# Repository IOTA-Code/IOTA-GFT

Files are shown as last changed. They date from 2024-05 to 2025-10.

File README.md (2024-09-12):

# IOTA-GFT Project
----------------------------
The IOTA-GFT project (IOTA GPS Flash Timer) implements a GPS based solution for adding UTC timestamps to sequential image captures (e.g. video).  The project includes both an IOTA-GFT hardware device and various software components for the computer used to capture the video data.

The IOTA-GFT device connects to the video recording computer and drives an LED which is attached to the front of the optics.  The IOTA-GFT software on the recording computer controls the LED flash sequence from the device and logs the timing information from the IOTA-GFT device.  After recording a video sequence, this recording computer IOTA-GFT software analyzes the video and timing log to determine the times for each video frame.

This repository includes the following components:
- IOTA-GFT Device
    - Device Firmware
    - IOTA-GFT Shield PCB design
    - LED bracket components
- Recording computer software ( *** NOT YET ADDED TO THIS REPO ! )
    - ASCOM Driver for the IOTA-GFT device
    - FileStamper utility for inserting timestamps
- Documentation
    - Usage Guide(s) - also TBD !

## Licensing
------------
 This program is free software: you can redistribute it under the terms of the GNU General Public License as published by the Free Software Foundation, either version 3 of the License, or (at your option) any later version.  However, if you wish to make modifications, we add a further restriction.  If you make changes to the code from this repository, you must agree to NOT use the modified code for timing occultation observations.

 This program is distributed in the hope that it will be useful, but WITHOUT ANY WARRANTY; without even the implied warranty of MERCHANTABILITY or FITNESS FOR A PARTICULAR PURPOSE.  See the GNU General Public License for more details.

## Developers & Contributors
----------------------------

- Bob Anderson
- Steve Preston

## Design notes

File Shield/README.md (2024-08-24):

# IOTA-GFT Shield
----------------------------
The IOTA-GFT Arduino shield includes the GPS receiver and driver circuit for the LED.  This shield is designed for and requires an Arduino Mega 2560 R3 board.  The IOTA-GFT controller consists of this shield mounted on an Arduino Mega.  This repository carries the Eagle design files for the shield.

## Components
--------------
- IOTA-GFT shield PCB
- Female stacking headers for Arduino Mega ( https://a.co/d/8ICgdAu )
- GT-U7 GPS breakout board based on ublox GPS receiver (https://a.co/d/9eoqRfC) 
- Active GPS Antenna + pigtail ( https://a.co/d/hI4Iglh )
- SparkFun Voltage-Level Translator Breakout - TXB0104 ( https://www.sparkfun.com/products/11771 )
- (2) seven pin male headers - 0.1" (can break off from longer header : https://a.co/d/7kpX5g9 )
- (1) six pin male header - 0.1"
- (2) JST-XH PCB jack , CONN HEADER VERT 2POS 2.5MM, JST part# B2B-XH-A ( https://www.digikey.com/short/nwvmtq8r )
- Resistors (1/4w)
  - (1) 150 ohm
  - (1) 1k ohm
  - (1) 5.6k ohm
  - (1) 200k ohm
- Capacitors (50v)
  - (1) 30 pf
- Transistors
  - (1) 2N3906
- Plastic zip tie (4")

## Schematic and Board layout
------------
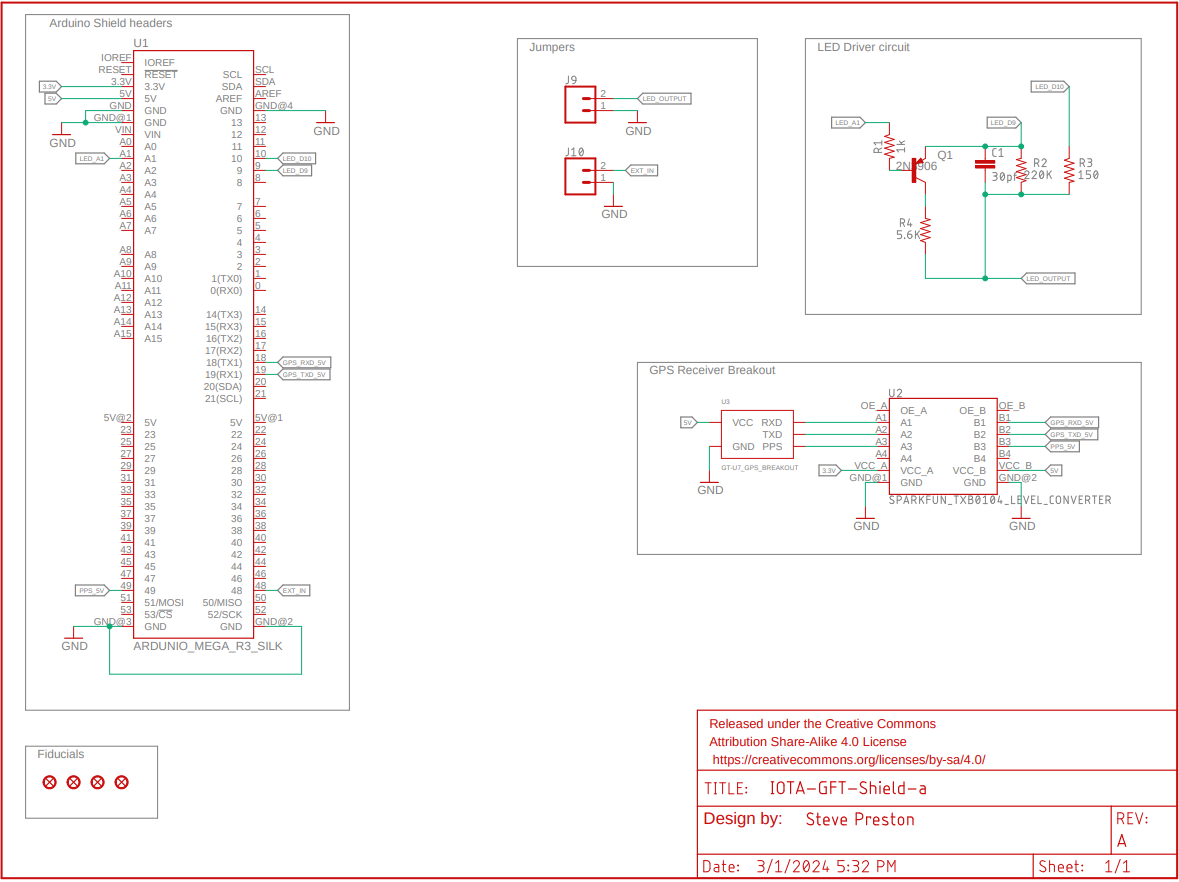
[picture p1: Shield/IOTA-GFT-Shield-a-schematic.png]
schematic

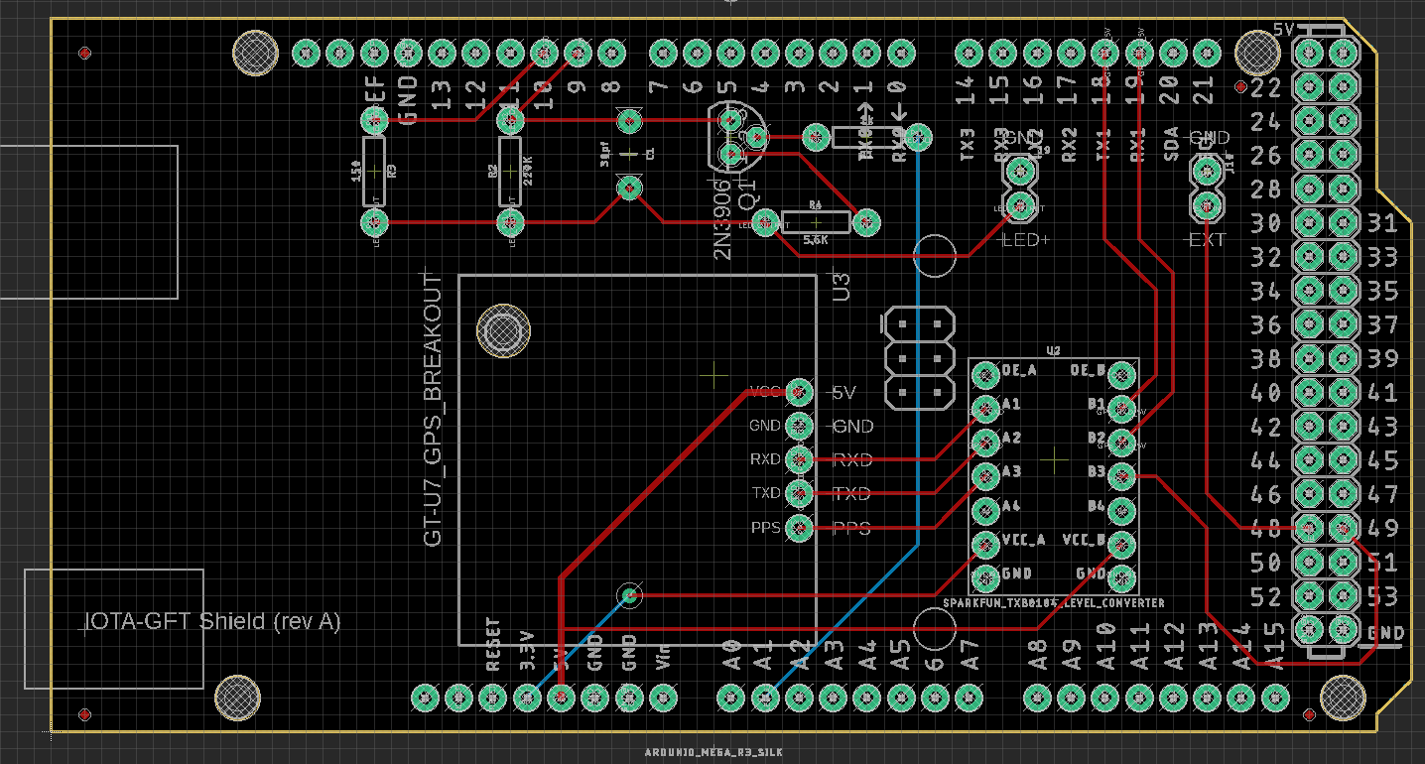
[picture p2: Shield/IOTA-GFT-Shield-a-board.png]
board layout


## Assembly
------------
- Solder the Arduino shield stacking headers onto the PCB.
- Solder the two 7 pin male headers onto the PCB at the location of U2 (level shifter)
- Solder the one 6 pin male header onto the PCB at the location of the pins for the GT-U7 breakout board.
- Solder the resistors, capacitor, and transitor onto the PCB at the marked locations.
- Solder the two JST connectors onto the PCB with the open side facing away from the Arduino's USB and power connectors.
- Solder the TXB0104 breakout board onto the two male headers with the OE marked end facing the two JST connectors.
- Attach the GPS antenna pigtail to the antenna connector on the GT-U7 breakout board.
- Solder the GT-U7 GPS breakout board to the single six pin male header.
- Snug down the GPS antenna pigtail to the breakout board using the plastic zip tie.

## Licensing
------------
 This design is free: you can redistribute it under the terms of the GNU General Public License as published by the Free Software Foundation, either version 3 of the License, or (at your option) any later version.  However, if you wish to make modifications, we add a further restriction.  If you are going to use this design to measure times for occultation observations, you must agree to not modify the design.

 This design is distributed in the hope that it will be useful, but WITHOUT ANY WARRANTY; without even the implied warranty of MERCHANTABILITY or FITNESS FOR A PARTICULAR PURPOSE.  See the GNU General Public License for more details.

## Developers & Contributors
----------------------------
- Bob Anderson
- Steve Preston
- Aart Olsen

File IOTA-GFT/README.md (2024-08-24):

# IOTA-GFT Device
----------------------------
The IOTA-GFT device connects to the user's computer via USB and drives an LED which is attached to the front of the telescope.  The user's computer initiates sequences of LED "flashes" which illuminate a set of frames on recorded video sequences.  The IOTA-GFT device employs an internal GPS receiver to record the timing of the flash sequences and emit a log with timing information to the user's computer over the USB connection.  This same USB connection supplies power to the IOTA-GFT device. After video recording, this timing log is compared to the recorded video to determine the UTC times for each frame of the video recording.

The IOTA-GFT device hardware includes the following components:
- IOTA-GFT controller, USB cable, enclosure and USB cable
- Active GPS antenna
- LED bracket and 3.5mm pin cable

This repository holds the Arduino firmware for the IOTA-GFT controller.  The IOTA-GFT controller combines an Arduino Mega 2560 with the IOTA-GFT shield.

## Building and installing the IOTA-Flasher firware
---------------------------------------------------
Prerequisites:
- Arduino IDE

Build and Install Steps:

Open the file "IOTA-GFT.ino" in the Arduino IDE.  Connect the IOTA-GFT device to your build computer via USB.  Then, in the Arudino IDE, connect to the IOTA-GFT device and upload the firmware (this will automatically start with a build before uploading).

## Licensing
------------
 This program is free software: you can redistribute it under the terms of the GNU General Public License as published by the Free Software Foundation, either version 3 of the License, or (at your option) any later version.  However, if you wish to make modifications, we add a further restriction.  If you are going to use this device to measure times for occultation observations, you must agree to not modify the code from this repository.

 This program is distributed in the hope that it will be useful, but WITHOUT ANY WARRANTY; without even the implied warranty of MERCHANTABILITY or FITNESS FOR A PARTICULAR PURPOSE.  See the GNU General Public License for more details.

## Developers & Contributors
----------------------------
- Bob Anderson
- Steve Preston

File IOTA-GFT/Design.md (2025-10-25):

# IOTA-GFT Design Document
This design document provides an overview of the basic theory of operation for the IOTA-GFT device.  
## Components
The IOTA-GFT comprises the following components:
- PIC microprocessor (Arduino Mega 2560)
- GPS receiver (ublox)
- Serial I/O to an external computer via USB
- LED driver circuit for driving an external LED
- Optional input from an external 5V logic trigger signal
## General Overview
The IOTA-GFT collects timing information from the PIC microprocessor, the GPS receiver, and (optionally) the external trigger input.  This timing information, or timing log, is sent across the USB connection to the recording computer where it is stored and later used to determine the UTC time of various system events.  Each line of output in this timing log, from the IOTA-GFT device, includes a timestamp and a data content portion.  The log timestamps are 32 bit counts (in hex) from the 16mhz system timer of the PIC processor. The IOTA-GFT emits logging sentences with the system time for each of the following system events:
- GPS data
    - NMEA sentences via serial I/O comm with the GPS receiver
    - PPS via 1pps signal generated by the GPS receiver
- LED activity
    - LED turns ON
    - LED turns OFF
- External input trigger (EXP signal)
- USB Commands
    - USB Commands sent to the device
    - Device responses to USB Commands 
## Operating Modes
The IOTA-GFT firmware implements a simple state machine with five "operating modes": InitMode, WaitingForGPS, Syncing, TimeValid, and FatalError.  The device boots into InitMode and quickly transitions to WaitingForGPS.  In WaitingForGPS mode, the code monitors the NMEA data and PPS signal waiting until both of these inputs imply that the GPS data is deemed "valid" for timing purposes.  At this point, the device moves to "Syncing" mode where it monitors several seconds of data to confirm that the GPS data is stable.  Assuming the GPS data looks good for several seconds of Syncing mode, the device moves to TimeValid mode and is ready for operation.  If transient errors occur (e.g. bad NMEA data or missing PPS pulses), the device will drop back to WaitingForGPS mode to "restart" toward TimeValid mode.  The FatalError mode only occurs in case of a non-recoverable error (e.g. unable to initialize the GPS receiver).State changes, between the five operating modes, are primarily driven by the GPS receiver - both the NMEA data and the PPS interrupt.

The IOTA-GFT firmware follows the standard Arduino coding structure: a one-time setup() routine and a loop() routine which is exectued repeatedly.  The setup() routing initializes the GPS receiver, the Arduino timer/counters, the Arduino I/O ports and various other elements.  The loop() routine repeatedly checks for input from the GPS receiver and the USB serial from the recording computer.  In addition, the loop() routine regularly outputs pending timing log data to the recording computer. 

## Timers
IOTA-GFT uses five of the Arduino timer/counters: Timer 0, Timer 2, Timer 3, Timer 4 and Timer 5.

Timer 0 is the default Arduino timer for the delay() and millis() functions.  These functions are used in the gps communication code.

Timer 2 is used in PWM mode to implement a software based intensity control for the LED.

Timer 3 is used for LED pulse duration in certain flash modes.

Timer 4 and Timer 5 are synchronized system timer counters running at 16 mhz.  The Input Capture signal for Timer 4 is tied to the PPS input. The Input Capture signal for Timer 5 is tied to the EXP signal input.  The firmware uses the overflow interupts to implement 32 bit system timers based on Timer 4 and 5.  Because these timers are synchronized, both system time counts are always identical.  The input capture register assures that the PPS and EXP interupt times are highly accurate (no latency to the ISR routine).

## Logging buffer
All information which is output to the recording computer (via USB serial) is first placed in an internal buffer.  The buffer is output to the recording computer during each pass through the main loop() routine.  Most of the logging sentences will be written to the buffer without interruption.  However, logging based on PPS and EXP interrupts might "interrupt" another sentence in the log.

## Flash Operation
The IOTA-GFT is designed to support three flash modes: CLK, PPS and EXP.  The majority of users will use CLK flashes.  The EXP mode is currently in development.  It is aimed at cameras which provide an output signal marking the beginning of an exposure.  

IOTA-GFT operates in CLK flash mode by default.  Flash sequences are specified as X seconds long.  When a "flash now" command is sent to the device in CLK mode, the LED turns on immediately and turns OFF X seconds later according to the internal device clock.

In either flash mode, the device can be programmed to a wide range of flash intensity values.

In addition, there is an option to turn the LED ON and OFF via explicit commands from the recording computer (over the USB port).

## LED Driver Circuit
The LED intensity is controlled via two appoaches: a LED current control "driver" circuit and a PWM modulation of the power driving this LED driver circuit.  The LED driver circuit is documented in the schematic for the PCB.

## USB I/O Device Commands
The recording computer sends commands to the IOTA-GFT over the USB connection. Commands are terminated with a LF (linefeed) character ('\n').  The commands may optionally include an XOR checksum in the form of "*XX" where XX are two ASCII hex chars for the one byte checksum. Commands are NOT case sensitive.

IOTA-GFT will return two sentences to all commands.  The first sentence will be an echo of the command sent to the device.  The second sentence will be a response to the command and include a simple one byte XOR checksum (two ASCII hex chars) at the end, followed by CR,LF ('\r\n'). Successful responses will be either the sentence "[DONE]" or "[command: value]".  Error responses will be of the form "[ERROR ...".  

### general commands
    status - get current device mode (e.g. TimeValid, WaitingForGPS, Syncing, etc)
    device - get device name
    version - get version info for the device
    null - ignore this command string if it includes the word "null" - useful for clearing the input buffer

 ### flash commands
    flash now - start flash sequence at the next PPS or EXP pulse
    flash duration X - X is seconds in PPS mode or starting number of pulses in EXP mode
    flash level X - get/set the current flash intensity level [ 0 to 255]
    flash range [X] -get/set the current range of flash intensity to low, medium or high [ 0 to 2]
    flash mode [clk | pps | exp ] - get/set the current flash mode (CLK, PPS or EXP)

    pulse duration [X] - get/set the flash pulse duration (us)
    pulse interval [X] - get/set the flash pulse interval = # of exp interrupts between pulse sequences

    led [ON | OFF] - turn the LED on/off right now

 ### logging commands
    log [on | off ] - enable disable data logging (default = ON)

## Timing Log Format
After startup, the IOTA-GFT constantly emits logging information - a timing log.  The timing log includes all NMEA data from the GPS receiver, all PPS and EXP interrupts, all LED flash timing, all commands sent to the device, all responses to these commands, and a regular report on the current operating mode of the device.  Each of these outputs is in the form of a single line of ASCII characters terminated with a *XX checksum and CRLF characters.

### Operating mode sentence
IOTA-GFT will output an operating mode sentence at the start of each set of NMEA sentences (which occur at the beginning of each UTC second).  

The format (excluding the terminating CRLF):

{MODE LED=L fff mmm}*XX
- L = current status of LED, 0=OFF, 1= ON
- fff = current flash mode (CLK, PPS or EXP)
- mmm = operating mode 
- XX = hex checksum in ASCII

examples: 
- {MODE LED=0 CLK Sync}*11
- {MODE LED=0 CLK TimeValid}*55

At power-up, IOTA-GFT emits the following sentence to the logging stream:

[STARTING!]*27

### GPS NMEA sentences
IOTA-GFT outputs a log sentence for each of the following NMEA sentences: $GPDTM, $GPRMC, $GPGGA, $PUBX04 (proprietary ublox sentence).  

The format (excluding terminating CRLF):

{TTTTTTTT nnn}*XX
- TTTTTTTT = 8 digit Hex system timer count when NMEA data received
- nnn = NMEA sentence data (without terminating CR or LF)
- XX - hex checksum in ASCII

examples:
- {006F03C0 $GPDTM,W84,,0.0,N,0.0,E,0.0,W84*6F}*37
- {00702831 $GPRMC,211252.00,A,4738.34269,N,12214.22164,W,0.114,,- 140324,,,A*64}*41
- {00725188 $GPGGA,211252.00,4738.34269,N,12214.22164,W,1,08,1.14,32.3,M,-18.7,M,,*51}*7C
- {0074B4E8 $PUBX,04,211252.00,140324,421972.00,2305,18,-305489,101.109,21*3D}*6A

### Interrupt timing sentences
An interrupt timing sentence is logged at the time of PPS and EXP interrupts.  These interrupt sentences are injected into the logging buffer at "interrupt level" and may sometimes appear "inside" other sentences (interrupting another logging sentence).

The format (excluding terminating CRLF):

{TTTTTTTT P}*XX
- TTTTTTTT = 8 digit Hex system timer count at time of interrupt
- P => this is a PPS interrupt
- XX - hex checksum in ASCII

{TTTTTTTT E}*XX
- TTTTTTTT = 8 digit Hex system timer count at time of interrupt
- E => this is an EXP interrupt
- XX - hex checksum in ASCII

Example:
- {1550D7B3 P}*75

### Flash timing sentences
A flash timing sentence is logged whenever the LED changes state (from OFF to ON or from ON to OFF).

The format (excluding terminating CRLF):

{TTTTTTTT +}*XX
- TTTTTTTT = 8 digit Hex system timer count when flash changed state
- '+' => LED turned ON
- XX - hex checksum in ASCII

{TTTTTTTT !}*XX
- TTTTTTTT = 8 digit Hex system timer count when flash changed state
- ! => LED turned OFF at the end of a flash sequence
- XX - hex checksum in ASCII

{TTTTTTTT -}*XX
- TTTTTTTT = 8 digit Hex system timer count when flash changed state
- '-' => LED turned OFF as part of a multi-flash sequence
- XX - hex checksum in ASCII

Example:
- {1550D7CB +}*7E

### Commands/Responses
Commands sent to the device will be echoed to the logging stream and enclosed in square brackets ('[', ']') and starting with the phrase CMD and a terminating checksum.  Responses to these commands are also returned in square backets and include a checksum.

example:
- [CMD flash now]*4A
- [DONE]*06

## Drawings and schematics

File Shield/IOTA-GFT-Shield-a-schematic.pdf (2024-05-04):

5V 5V | RESET RESET | A0 A0 | A1 A1 | A2 A2 | A3 A3 | A4 A4 | A5 A5 | A6 A6 | A7 A7 | A8 A8 | A9 A9 | A10 A10 | A11 A11 | A12 A12 | A13 A13 | A14 A14 | A15 A15

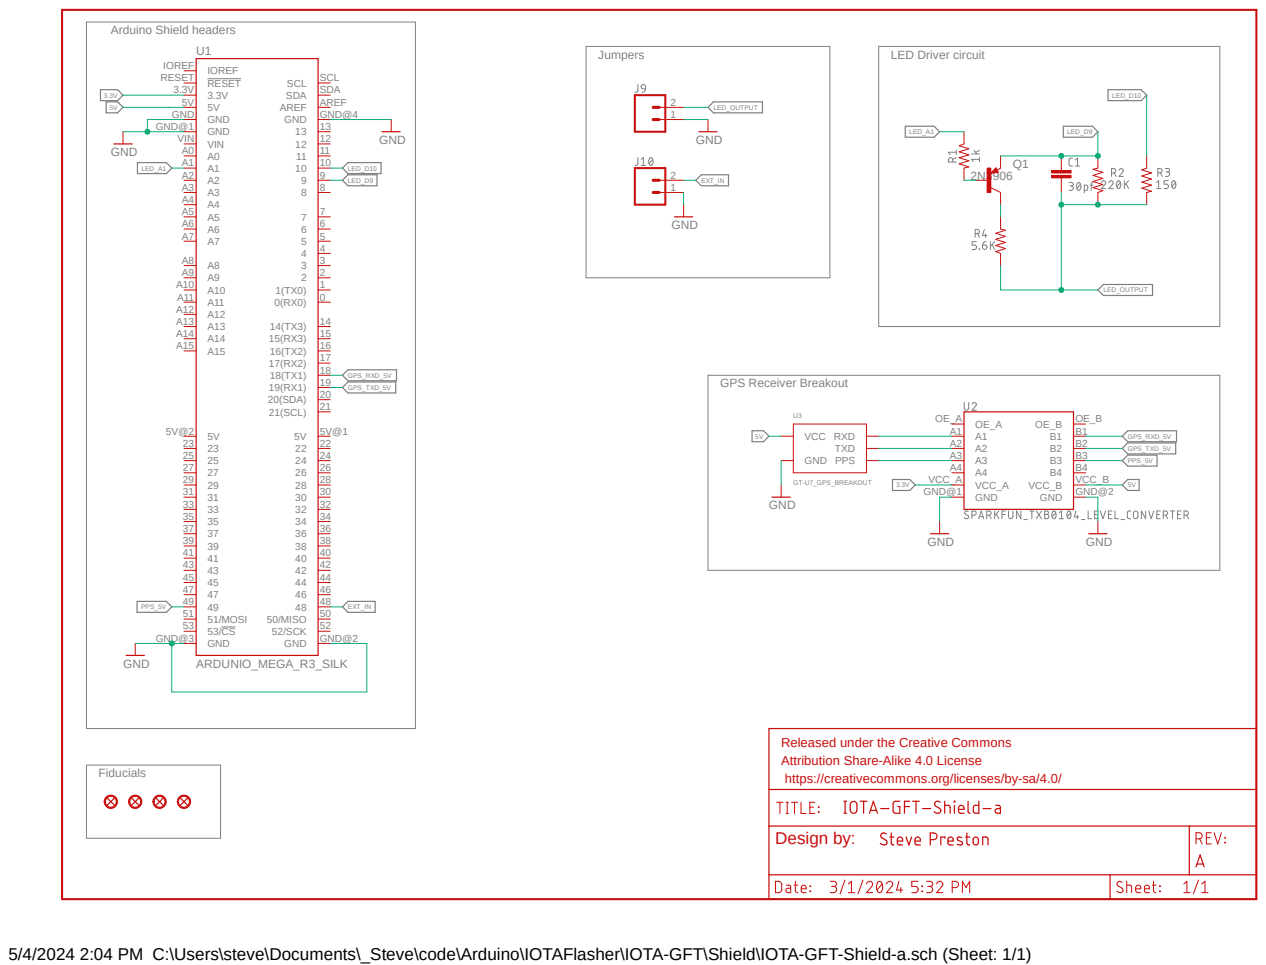
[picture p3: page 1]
Jumpers; LED Driver circuit; Fiducials; GND; ARDUNIO_MEGA_R3_SILK; GNDGT-U7_GPS_BREAKOUT; 14 GND GND@1; 52/SCK; 52 51/MOSI 51; 50/MISO; AREF; 21(SCL); 21 20(SDA); VIN VIN; 0 GND; GND@4 GND GND; SDA; SDA SCL; SCL IOREF IOREF; 5V@1 GND GND@3; GND@2; B4 VCC_B; VCC_B; VCC_A VCC_A; GND GND@1; GND@2 VCC GND; RXD TXD; PPS U3; LED_D9; LED_D10; LED_A1; LED_OUTPUT; LED_OUTPUT EXT_IN; EXT_IN; GPS_RXD_5V GPS_RXD_5V; GPS_TXD_5V GPS_TXD_5V; PPS_5V; Released under the Creative Commons; Design by:

Arduino Shield headers

GPS Receiver Breakout

Attribution Share-Alike 4.0 License
https://creativecommons.org/licenses/by-sa/4.0/

5/4/2024 2:04 PM C:\Users\steve\Documents\_Steve\code\Arduino\IOTAFlasher\IOTA-GFT\Shield\IOTA-GFT-Shield-a.sch (Sheet: 1/1)

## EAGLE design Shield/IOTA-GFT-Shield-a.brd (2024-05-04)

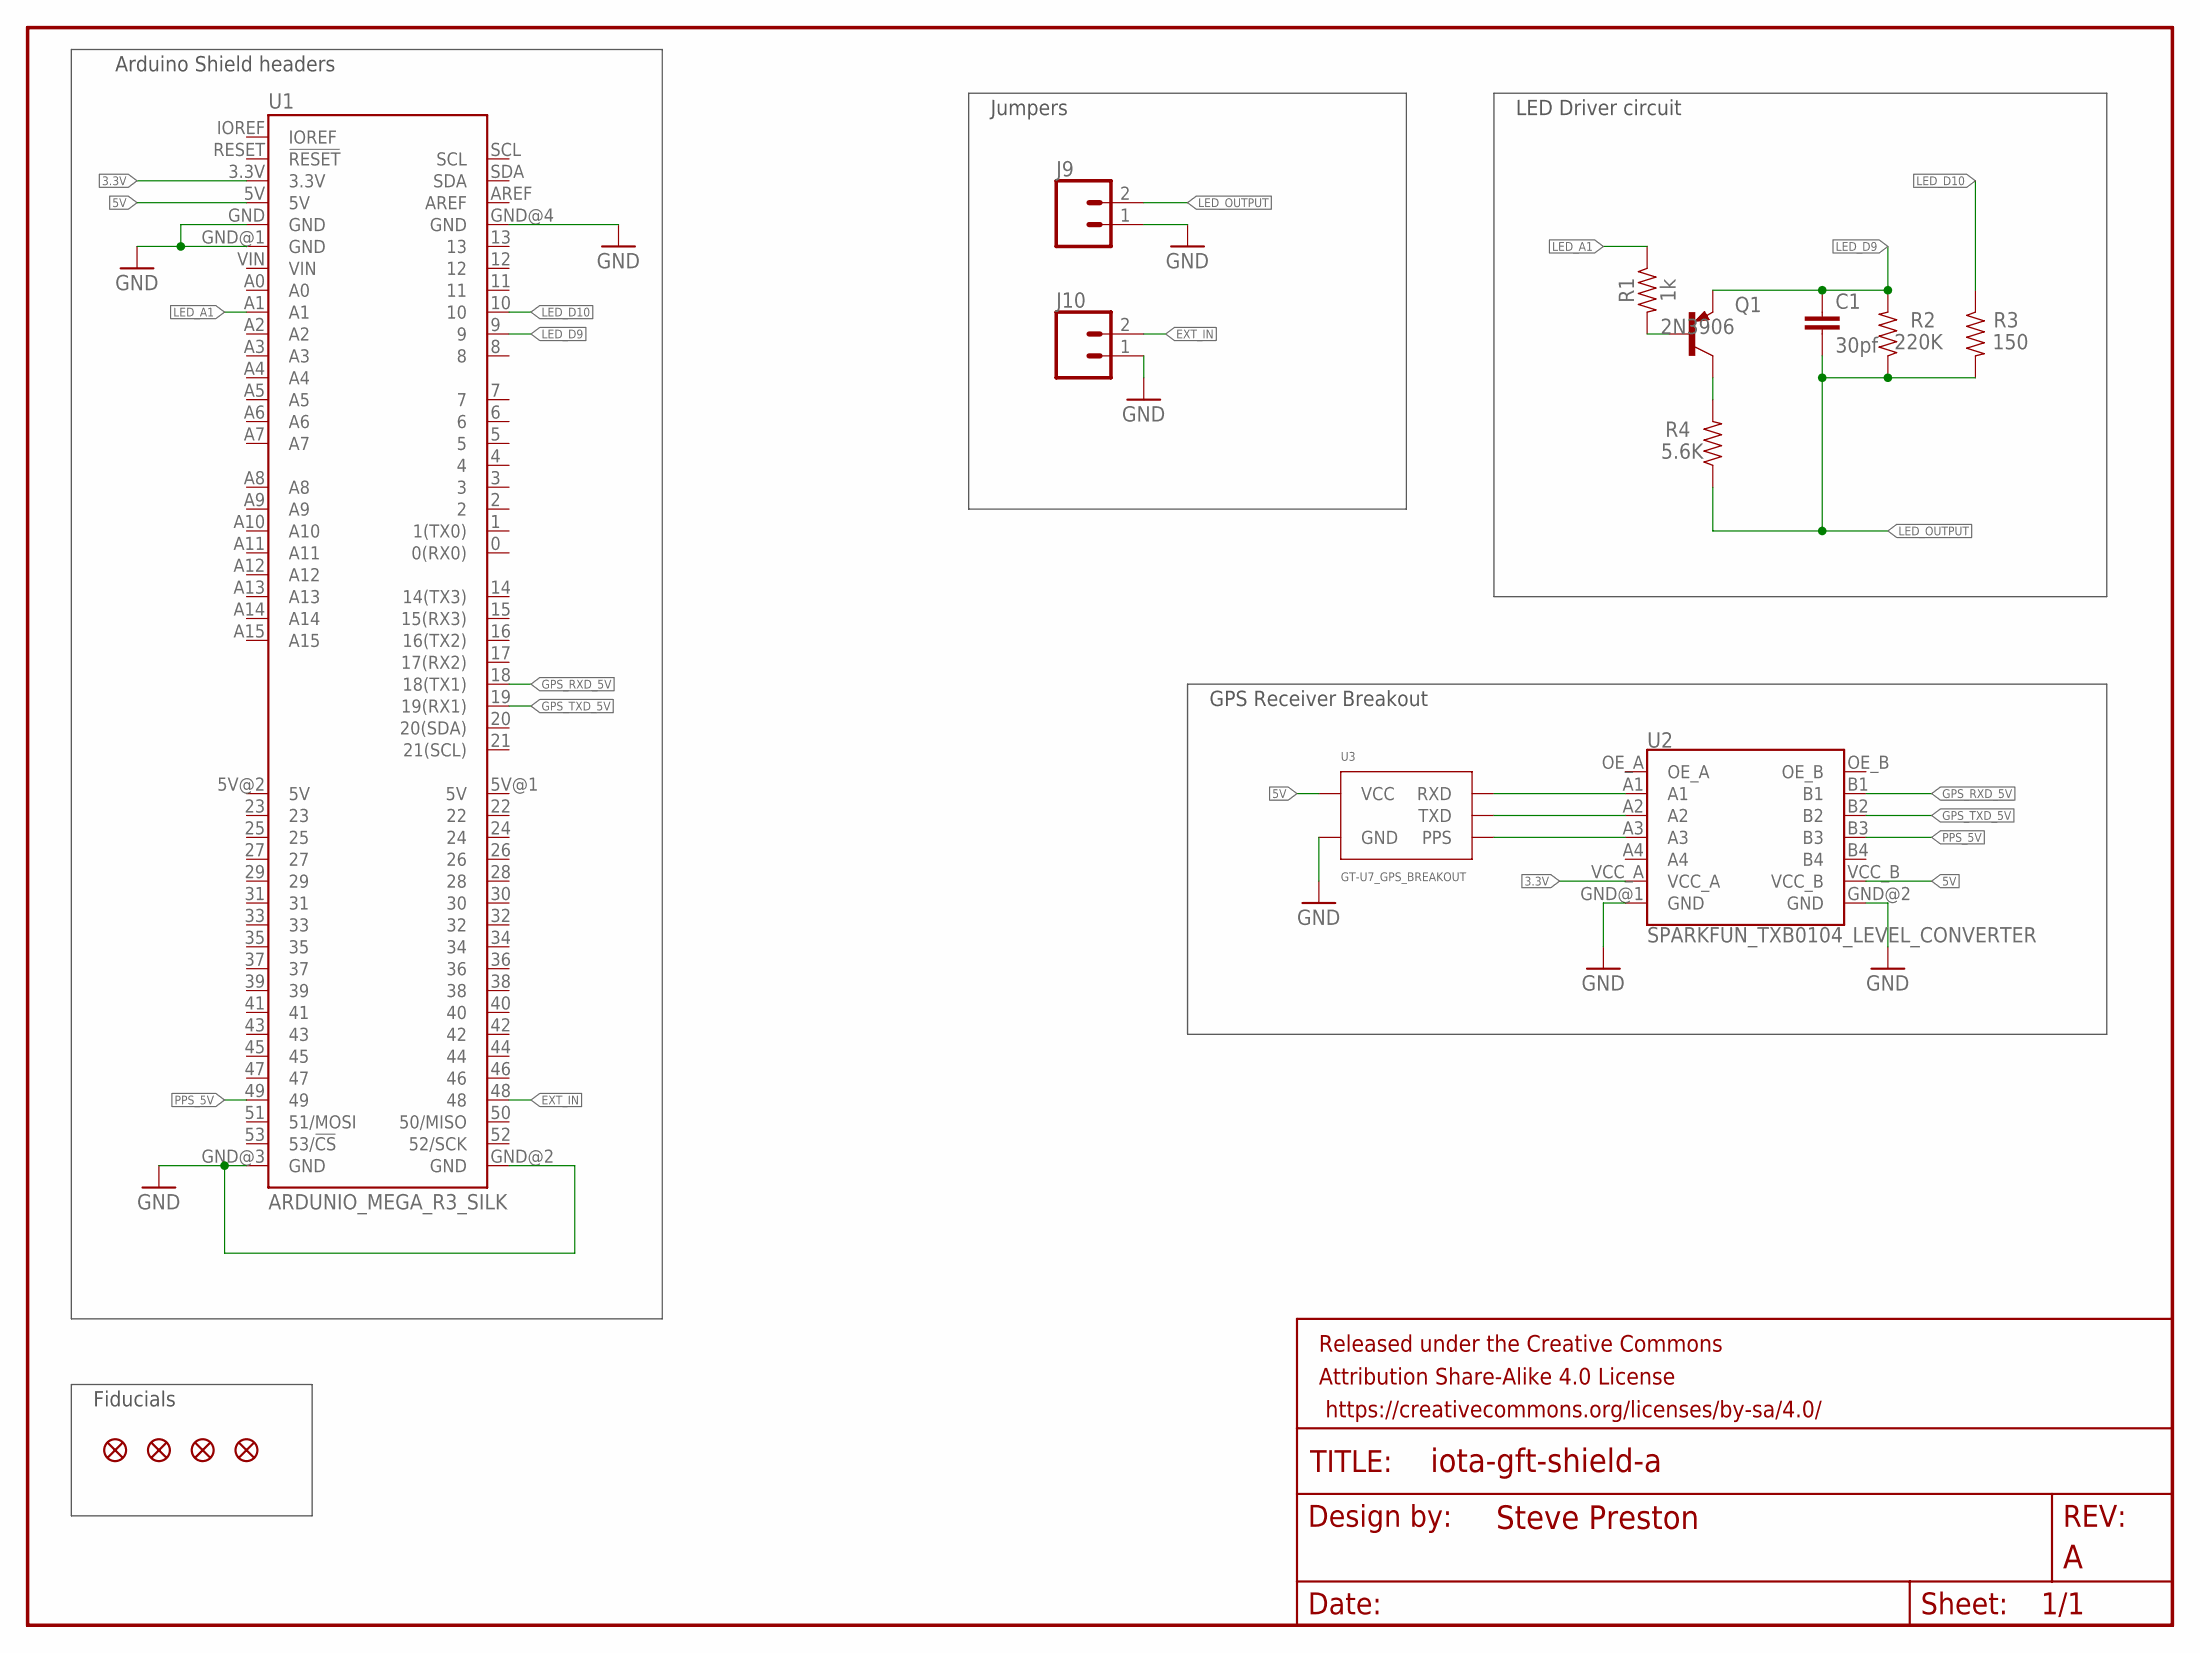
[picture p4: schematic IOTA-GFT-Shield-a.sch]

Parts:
C1: 30pf; CAP-PTH-5MM
FD1, FD2, FD3, FD4: FIDUCIALUFIDUCIAL; FIDUCIAL-MICRO
FRAME1: FRAME-LETTER; CREATIVE_COMMONS
J9, J10: CONN_02; 1X02
Q1: 2N3906; TO92
R1: 1k; AXIAL-0.3
R2: 220K; AXIAL-0.3
R3: 150; AXIAL-0.3
R4: 5.6K; AXIAL-0.3
U1: ARDUNIO_MEGA_R3_SILK; ARDUINO_MEGA_SILK
U2: SPARKFUN_TXB0104_LEVEL_CONVERTER; TXB0104_LEVEL_CONVERTER
U3: GT-U7_GPS_BREAKOUT; GT-UT

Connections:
3.3V: U1.3.3V, U2.VCC_A
5V: U1.5V, U2.VCC_B, U3.VCC
EXT_IN: J10.2, U1.48
GND: J9.1, J10.1, U1.GND, U1.GND@1 (GND), U1.GND@2 (GND), U1.GND@3 (GND), U1.GND@4 (GND), U2.GND@1 (GND), U2.GND@2 (GND), U3.GND
GPS_RXD: U2.A1, U3.RXD
GPS_RXD_5V: U1.18 (18(TX1)), U2.B1
GPS_TXD: U2.A2, U3.TXD
GPS_TXD_5V: U1.19 (19(RX1)), U2.B2
LED_A1: R1.P$1 (1), U1.A1
LED_D9: C1.1, Q1.3 (E), R2.P$2 (2), U1.9
LED_D10: R3.P$1 (1), U1.10
LED_OUTPUT: C1.2, J9.2, R2.P$1 (1), R3.P$2 (2), R4.P$1 (1)
unnamed: Q1.1 (C), R4.P$2 (2)
unnamed: Q1.2 (B), R1.P$2 (2)
PPS: U2.A3, U3.PPS
PPS_5V: U1.49, U2.B3

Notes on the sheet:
Jumpers
LED Driver circuit
Arduino Shield headers
GPS Receiver Breakout
Fiducials

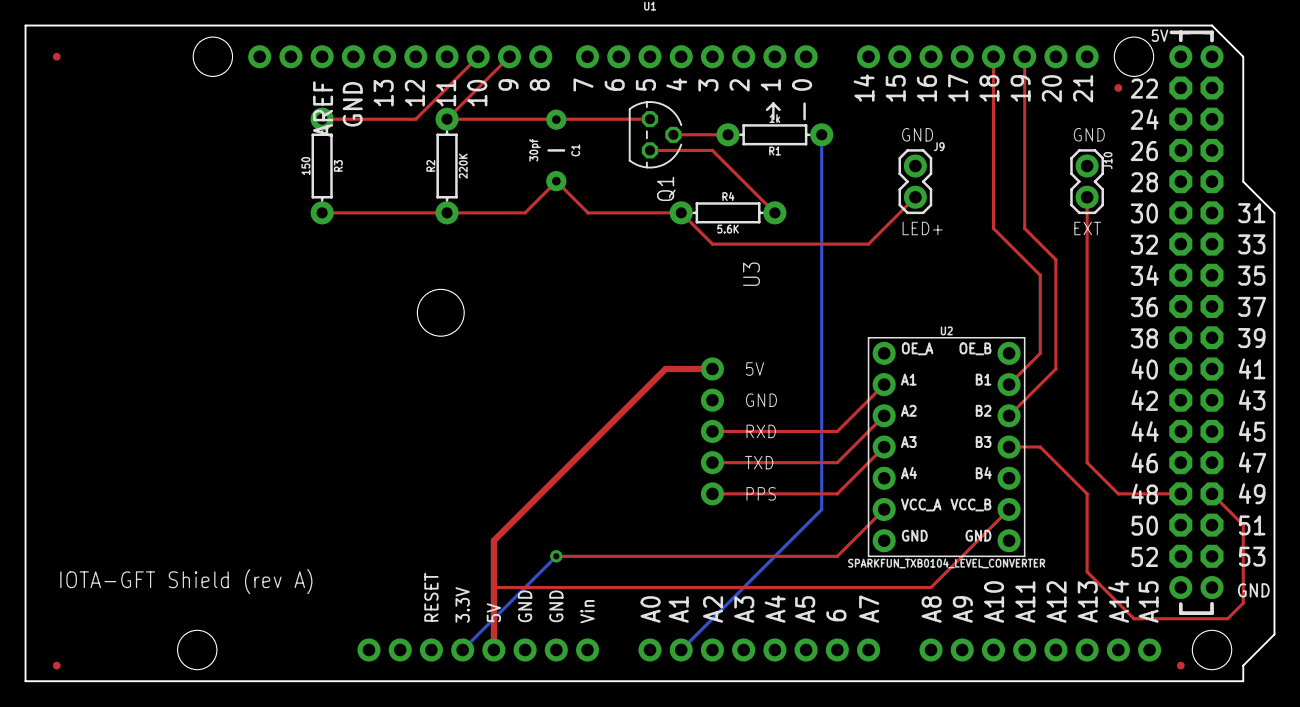
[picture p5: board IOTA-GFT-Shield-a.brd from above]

Board: 2 copper layers, 101.6 x 53.3 mm, 16 parts (0 on the bottom side), 16 nets.

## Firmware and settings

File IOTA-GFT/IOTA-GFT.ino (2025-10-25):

//======================================================================
//  IOTA-GFT - GPS Exposure TIME LOGGER
//  
//  NOTES: 
//  *** ASSUMES NEO-6 GPS module
//  *** ASSUMES MEGA2560 R3 Arduino
//   
//
//====================================================================== 
//
//

// Mega Pin Connections
//
//  GPS comm
//   Connect the GPS TX (transmit) to Digital pin 19 (RX1)
//   Connect the GPS RX (receive) to Digital pin 18 (TX1)
//   Connect the GPS 1pps Digital pin 49 (ICP4)
//
//	Exposure start signal
//   Connect the Digital pin 48 to the exposure interrupt input (or GND if no exposure int input).  Most cameras will require a pull-up resistor.
//
//  LED
//   Connect Digital pin 9, Digital pin 10, and Analog pin 1 to the LED driver circuit
//   
//
// 


//=======================================
//  INCLUDES
//=======================================
#include "iota-gft.h"
#include "ublox.h"
#include "gpsComm.h"
#include "logger.h"
#include "usbComm.h"

//==========================================
// PIN definitions
//===========================================
int PPS_PIN = 49;           // PPS signal input from GPS
int EXP_PIN = 48;           // EXP signal input from camera

  // LED circuit pins
#define flashPinB 9        // This PWM pin is controlled by OCR2B
#define flashPinA 10       // This PWM pin is controlled by OCR2A

#define midRange  55       // Controls switch transistor that provides middle current for LED (D55 = Analog 1)

//=======================================
//  GLOBAL variables and definitions
//=======================================

//  VERSION
//
const char *strDeviceName = "IOTA-GFT";
const char *strVersion = "v2024-04-01-01";

volatile OperatingMode DeviceMode;    // current operating mode
volatile bool blnReportMode;          // true => report current mode in log (enabled with each NMEA set)

unsigned long tBeginWait;
bool fStarted;                        // set to true when we first enter TimeValid mode


volatile FlashingMode FlashMode;		// current flashing mode

short int SYNC_SECONDS = 4;            // # of seconds for syncing to GPS time
volatile short int TimeSync;          // ( > 0 ) => we are syncing to GPS sentence times = # of seconds remaining for sync (small value so no problem with ints)



//******************
// Timers
//

volatile unsigned short timer4_ov;    // timer 4 overflow count = high word of "time" (32ms)
volatile unsigned short timer5_ov;    // timer 5 overflow count  

byte flashlevel = 255;                    // flash brightness level in percent (0 to 255)
byte flashrange = 2;                      //  range of flash intensity ( 0 - 2 )

uint16_t Timer3_us = 16;				          // microseconds per led timer clock count (x256 prescaler)
uint16_t OCR3A_pulse = 5000/Timer3_us;    // default 5ms pulse duration for EXP mode

//*************
//  Time
//
volatile unsigned long Timer_Second = 2000000;                // # of ticks for 1 second
volatile unsigned long PPS_TOLERANCE = 2000;                  // tolerance for PPS interval - 1ms
volatile unsigned long CLOCK_TOLERANCE = 20000;               // tolerance for arduino clock frequency interval - currently 10ms

volatile unsigned long tk_pps_interval_total=0;         // sum of pps intervals
volatile unsigned long tk_pps_interval_count=0;         // # of pps interval
volatile unsigned long tk_pps_interval_ave=0;           // average pps interval

// YY-MM-DD HH:MM:SS time of current second
//   note: all values are less than 255 => don't need to protect individual changes from interrupts during read/write
//         an ISR might use these values, so we should only update the groups of these variables with interrupts OFF
//
volatile bool time_UTC = false;         // true => time is currently UTC , false => time is currently GPS
volatile int sec_Year;                  // 2 digit
volatile int sec_Mon;
volatile int sec_Day;
volatile int sec_hh;
volatile int sec_mm;
volatile int sec_ss;
volatile int offsetUTC_Default = -1;      // receiver default value for GPS-UTC offset
volatile int offsetUTC_Current = -1;      // current/valid GPS-UTC offset


//***************
// PPS globals
//
volatile unsigned long tk_PPS = 0;        // tick "time" of most recent PPS int

//****************************
// Flash variables
//    There are three flashing modes: CLK, PPS and EXP.  In all cases, the LED is driven by a PWM cycle.
//    CLK mode => Flashes are single LED On/Off sequences (via PWM) where the LED is turned ON immediately and turns off after X seconds according to the internal clock.
//    PPS mode => Flashes are single LED On/Off sequences (via enabing/disabling PWM) where both the start and stop are closely aligned with a PPS signal.
//    EXP mode => Flashes are a series of short duration LED On/Off pulses
//    
//
volatile boolean LED_ON = false;      			// LED state

volatile int PPS_Flash_Countdown_Sec;           // # of seconds remaining in a PPS or CLK flash
                                                //  (countdown < 0) => not in PPS or CLK flash sequence

                                            // EXP flash sequences are short pulses separated by D EXP intervals for a total count of X pulses
                                            //      sequence is enabled when pulse_countdown is non-zero
                                            //
int pulse_duration_us = 5000;               // duration of one shutter (EXP) pulse in EXP mode
volatile int pulse_interval = 5;            // number of EXP events between pulses
volatile int pulse_countdown;               // # of pulses left in sequence, 0 => no EXP flash sequence in progress, (< 0 => no sequence active)
volatile int pulse_interval_countdown;      // # of EXP events until next pulse, 0=> flash (pulse) on next EXP event



//*********
//  INPUTS
//
volatile bool blnEchoNMEA = false;


//********
//  serial outputs
//

char logPPS[] = "{TTTTTTTT P}*XX\r\n";
int len_logPPS = 17;
int offset_logPPS = 1;
int chksum_logPPS = 13;

char logEXP[] = "{TTTTTTTT E}*XX\r\n";
int len_logEXP = 17;
int offset_logEXP = 1;
int chksum_logEXP = 13;

char logFlashON[] = "{TTTTTTTT +}*XX\r\n";
int len_logFlashON = 17;
int offset_logFlashON = 1;
int chksum_logFlashON = 13;

char logFlashOFF[] = "{TTTTTTTT -}*XX\r\n";
int len_logFlashOFF = 17;
int offset_logFlashOFF = 1;
int chksum_logFlashOFF = 13;

char logFlashFINAL[] = "{TTTTTTTT !}*XX\r\n";    // end of final flash pulse in sequence
int len_logFlashFINAL = 17;
int offset_logFlashFINAL = 1;
int chksum_logFlashFINAL = 13;

// mode sentences
//
int lmode_logMode = 10;     // offset to start of led mode - to be set to 0 or 1
int fmode_logMode = 12;    // offset to start of flash mode string 

char logModeInit[] = "{MODE LED=L FFF Init}*1F\r\n";
int len_logModeInit = 26;
int chksum_logModeInit = 22;

char logModeWaitingForGPS[] = "{MODE LED=L FFF WaitingForGPS}*71\r\n";
int len_logModeWaitingForGPS = 35;
int chksum_logModeWaitingForGPS = 31;

char logModeSync[] = "{MODE LED=L FFF Sync}*02\r\n";
int len_logModeSync = 26;
int chksum_logModeSync = 22;

char logModeTimeValid[] = "{MODE LED=L FFF TimeValid}*XX\r\n";
int len_logModeTimeValid = 31;
int chksum_logModeTimeValid = 27;

char logModeFatal[] = "{MODE LED=L FFF Fatal}*7B\r\n";
int len_logModeFatal = 27;
int chksum_logModeFatal = 23;

char logERROR[] = "{ERROR 0000}*XX\r\n";
int len_logERROR = 17;
int offset_logERROR = 7;
int chksum_logERROR = 13;


//+++++++++++++++++++++++++++++++++++++++++++++++++++++++++++++++++++++++++++
//
//  INTERRUPT SERVICE ROUTINES
//
//    Timer 3
//      output compare for LED pulse duration
//    Timer 4
//      input capture for PPS logging
//      overflow for tracking clock count
//    Timer 5
//      input capture for EXP logging
//      overflow for tracking clock count
//+++++++++++++++++++++++++++++++++++++++++++++++++++++++++++++++++++++++++++


//========================================
// ISR for LED done (timer 3 output compare A interrupt)
//=========================================
ISR(TIMER3_COMPA_vect)
{
  unsigned long tk_LED;
  byte chk;

  // should be either CLK or EXP flash mode
  //
  if (FlashMode == CLK)
  {
    // CLK mode
    //  if done with seconds, turn OFF LED and log it
    //  if not done, reset timer and continue

    // check status of CLK flash sequence
    //  countdown >= 0 => in a flash sequence
    //  countdown == 0 => time to disable flash
    //  countdown < 0 => not in flash sequence now

    if (PPS_Flash_Countdown_Sec > 0)
    {
      // inside a flash sequence 
	    //	reenable timer for another second of LED ON
	    //
	  
      // start flash timer = timer 3
      TCCR3B = (1 << WGM32);                  // CTC set => mode 4 AND CS = 0 (no input => clock stopped)
      TCNT3 = 0;                              // start count at 0
      OCR3A = 0xFFFF;                         // set duration to 1 second
      TIFR3 = 0xFF;                           // clear any pending interrupts
      TCCR3B |= (1 << CS32);                  // f/256 clock source => timer is ON now   
      TIMSK3 |= (1 << OCIE3A);                // enable timer compare interrupt
	  
      // one less second left in this pulse
      //
      PPS_Flash_Countdown_Sec--;

    }
    else if (PPS_Flash_Countdown_Sec == 0)
    {
      // (Countdown == 0)  => flash should be disabled now
      //

      // if LED is ON, turn it OFF
      // else do nothing
      //
      if (LED_ON)
      {
        // no more flashes left
        //
        OCR2A = OCR2B = 0;                    // LED OFF
        tk_LED = GetTicks(CNT4);              // time LED turned OFF
        LED_ON = false;

        // LOG time LED went OFF
        //
        ultohexA(logFlashFINAL + offset_logFlashFINAL,tk_LED);
        chk = chksum_b(logFlashFINAL,chksum_logFlashFINAL-1);   // compute checksum
        btohexA(logFlashFINAL + chksum_logFlashFINAL, chk);
        LogTextWrite(logFlashFINAL,len_logFlashFINAL);


      }
      PPS_Flash_Countdown_Sec--;            //  decrement this count => no longer in flash sequence

    }  // end of check for seconds remaining

  }
  else if (FlashMode == EXP)
  {
    // EXP mode 
    //  end this pulse , update pulse count

    // turn OFF LED 
    //
    OCR2A = OCR2B = 0;
    LED_ON = false;

    // log time flash went off
    //
    tk_LED = GetTicks(CNT4);              // time LED turned OFF

    // turn OFF Timer 3
    //
    TCCR3B = (1 << WGM32);    // CTC set => mode 4 AND CS = 0 (no input => clock stopped)

    // note: interrupts are still disabled, so no issue with logging
    //
    if (pulse_countdown == 0)
    {
      ultohexA(logFlashFINAL + offset_logFlashFINAL,tk_LED);
      chk = chksum_b(logFlashFINAL,chksum_logFlashFINAL-1);   // compute checksum
      btohexA(logFlashFINAL + chksum_logFlashFINAL, chk);
      LogTextWrite(logFlashFINAL,len_logFlashFINAL);

      // all done with this pulse sequence now
      //
      pulse_countdown = -1;

    }
    else
    {
      ultohexA(logFlashOFF + offset_logFlashOFF,tk_LED);
      chk = chksum_b(logFlashOFF,chksum_logFlashOFF-1);   // compute checksum
      btohexA(logFlashOFF + chksum_logFlashOFF, chk);
      LogTextWrite(logFlashOFF,len_logFlashOFF);
    }

  }
  
} // end of LED_done_interrupt

//========================================
// ISR for Timer 4 overflow
//=========================================
ISR( TIMER4_OVF_vect)
{
  
  timer4_ov++;   // just increment overflow count
  
} // end of Timer4 overflow vector

//=================================================================
// PPS signal ISR
//
// ISR for Timer 4 input capture interrupt 
//==================================================================
ISR( TIMER4_CAPT_vect)
{

  unsigned long timeCurrent;
  unsigned long timePrev;
  unsigned long timeDiff;
  unsigned long ppsDiff;

  unsigned long tk_LED;       // LED time in ticks
  bool blnLogFlashON = false;
  bool blnLogFlashOFF = false;
  byte chk;

  
  //************************
  // Get TIME of PPS event from input capture register
  //
  timeCurrent = GetTicks(IC4);

  //*****************
  //  If init mode or FatalError, just leave...
  //
  if ((DeviceMode == FatalError) || (DeviceMode == InitMode))
  {
    // do nothing in these modes
    return;
  }

  // Check for start/end of LED pulse in PPS mode
  //
  //******************
  if (FlashMode == PPS)
  {

    // check status of PPS flash sequence
    //  countdown >= 0 => in a flash sequence
    //  countdown == 0 => time to disable flash
    //  countdown < 0 => not in flash sequence now
    if (PPS_Flash_Countdown_Sec == 0)
    {
      // (Countdown == 0)  => flash should be disabled now
      //

      // if LED is ON, turn it OFF
      // else do nothing
      //
      if (LED_ON)
      {
        // no more flashes left
        //
        OCR2A = OCR2B = 0;                    // LED OFF
        tk_LED = GetTicks(CNT4);              // time LED turned OFF
        LED_ON = false;

        // LOG time LED went OFF
        //
        ultohexA(logFlashFINAL + offset_logFlashFINAL,tk_LED);
        chk = chksum_b(logFlashFINAL,chksum_logFlashFINAL-1);   // compute checksum
        btohexA(logFlashFINAL + chksum_logFlashFINAL, chk);
        blnLogFlashOFF = true;

      }
      PPS_Flash_Countdown_Sec--;            //  decrement this count => no longer in PPS flash sequence

    }
    else if (PPS_Flash_Countdown_Sec > 0)
    {
      // (Countdown > 0)  => flash should be enabled
      //
      // if (LED OFF)
      //   turn it on
      //
      if (!LED_ON)
      {
        OCR2A = OCR2B = flashlevel;
        tk_LED = GetTicks(CNT4);              // time LED turned ON
        LED_ON = true;

        // log time LED went ON
        //
        ultohexA(logFlashON + offset_logFlashON,tk_LED);
        chk = chksum_b(logFlashON,chksum_logFlashON-1);   // compute checksum
        btohexA(logFlashON + chksum_logFlashON, chk);
        blnLogFlashON = true;

      }

      // one less second left in this pulse
      //
      PPS_Flash_Countdown_Sec--;

    } // end of LED status update

  } // end of check for PPS flash mode

  // save the previous value for compare
  //
  timePrev = tk_PPS;
  tk_PPS = timeCurrent;
  if (timePrev == 0)
  {
    // startup -> set timePrev to expected value to avoid meaningless error check on first PPS interval
    //
    timePrev = timeCurrent - Timer_Second;
  }

  // log the PPS time
  //
  ultohexA(logPPS + offset_logPPS,tk_PPS);
  chk = chksum_b(logPPS,chksum_logPPS-1);   // compute checksum
  btohexA(logPPS + chksum_logPPS, chk);
  LogTextWrite(logPPS,len_logPPS);

  //*****************
  //  DISABLE FURTHER PPS interrpts at ICP pin and ENABLE system interrupts
  //  *** WARNING - RE-ENABLE the PPS interrupts before leaving this ISR
  //
  TIMSK4 &= ~(1 << ICIE4);    // turn off ICP for timer 4 => no more PPS interrupts
  interrupts();               // enable interrupts again

  //************************************
  //  Validate PPS interval
  //    if too long or too short => Error Mode (PPS error)
  //   

  // delay from last PPS
  //
  if (timeCurrent > timePrev)
  {
    timeDiff = timeCurrent - timePrev;
  }
  else
  {
    timeDiff = 0 - (timePrev - timeCurrent);
  }
  
  // PPS interval between now and the last PPS
  //   save this to be used by averaging code
  //
  ppsDiff = timeDiff;       

  // check interval since last PPS
  // if Syncing , check delay since last PPS pulse...
  //  if too short or too long, restart SYNC
  // In other modes... just keep going and let the post-processing catch the errors
  //
  if (DeviceMode == Syncing)
  {
    if ((timeDiff < (Timer_Second - CLOCK_TOLERANCE)) || (timeDiff > (Timer_Second + CLOCK_TOLERANCE)))
    {
      // report error
      //
      ustohexA(logERROR + offset_logERROR,err_pps_interval_clock);
      chk = chksum_b(logERROR,chksum_logERROR-1);   // compute checksum
      btohexA(logERROR + chksum_logERROR, chk);
      noInterrupts();                                 // disallow interruption of this sentence in the log
      LogTextWrite(logERROR,len_logERROR);
      interrupts();

      // sync error - restart sync
      //
      tk_pps_interval_total = 0;
      tk_pps_interval_count = 0;

      DeviceMode = WaitingForGPS;
      TimeSync = SYNC_SECONDS;
      ppsDiff = 0;                // reset this to no error for now.


    }
  }
  else if (DeviceMode == TimeValid) 
  {
    if ((timeDiff < (Timer_Second - PPS_TOLERANCE)) || (timeDiff > (Timer_Second + PPS_TOLERANCE)))
    {
      // report error
      //
      ustohexA(logERROR + offset_logERROR,err_pps_interval_tolerance);
      chk = chksum_b(logERROR,chksum_logERROR-1);   // compute checksum
      btohexA(logERROR + chksum_logERROR, chk);
      noInterrupts();   // disallow interruption of this sentence in the log
      LogTextWrite(logERROR,len_logERROR);
      interrupts();
      // sync error - restart sync
      //
      DeviceMode = WaitingForGPS;
      TimeSync = SYNC_SECONDS;
      ppsDiff = 0;                // reset this to no error for now.

      tk_pps_interval_total = 0;
      tk_pps_interval_count = 0;
    }
  }



  // check to see if we should log the time of flash ON or OFF
  //
  if (blnLogFlashON)
  {
    noInterrupts();                                 // disallow interruption of this sentence in the log
    LogTextWrite(logFlashON,len_logFlashON);
    interrupts();
    blnLogFlashON = false;
  }
  if (blnLogFlashOFF)
  {
    noInterrupts();                                 // disallow interruption of this sentence in the log
    LogTextWrite(logFlashFINAL,len_logFlashFINAL);
    blnLogFlashOFF = false;
    interrupts();
  }


  //********************************
  // DeviceMode logic
  //
  //  *TimeValid
  //    Update internal time values
  //    - check for GPS/UTC switch
  //
  //  *WaitingForGPS Mode
  //    - if GPS data good
  //        move to Syncing mode
  //    - else
  //        leave (keep waiting)
  //
  //  *Syncing Mode
  //    - validate data and restart if necessary
  //    - NOTE: should always move here from WaitingForGPS => errors should go to WaitingForGPS mode first
  //
  //
  //
  if ( DeviceMode == TimeValid )
  {
    
    // TimeValid Mode
    //

    // update PPS interval statistics
    //
    tk_pps_interval_total += ppsDiff;
    tk_pps_interval_count++;

    // check for switch from GPS to UTC time
    //
    if (!time_UTC)
    {
      // time has been GPS based
      //  - do we have a valid almanac now?
      //
      if (gpsPUBX04.valid && gpsPUBX04.blnLeapValid)
      {
        // aha... we now have a current value for of GPS-UTC offset
        //  decrement time by this number of seconds and mark it as UTC time now...
        //
        for( int i = 0; i < gpsPUBX04.usLeapSec; i++)
        {
          SecDec();            
        }
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
void loop()                     // run over and over again
{
  int retVal;
  byte chk;
  //******************************************************
  //  check for pending data from GPS
  //
  retVal = ReadGPS();
  if ((retVal > 0) && (DeviceMode == TimeValid))
  {
    // report error
    //
    ustohexA(logERROR + offset_logERROR,retVal);
    chk = chksum_b(logERROR,chksum_logERROR-1);   // compute checksum
    btohexA(logERROR + chksum_logERROR, chk);
    noInterrupts();                                 // disallow interruption of this sentence in the log
    LogTextWrite(logERROR,len_logERROR);
    interrupts();

  }
  
  //***************************
  //  report current operating mode?
  //
  if (blnReportMode)
  {
    char *pS = logModeFatal;            // pointer to start of sentence
    int iChk = 0;                       // index of start of checksum chars
    int lenS = 0;                       // length of entire sentence to output
    char *p;

    // determine sentence offsets and pointers
    //
    if (DeviceMode == TimeValid)
    {
      pS = logModeTimeValid;
      iChk = chksum_logModeTimeValid;
      lenS = len_logModeTimeValid;
    }
    else if (DeviceMode == Syncing)
    {
      pS = logModeSync;
      iChk = chksum_logModeSync;
      lenS = len_logModeSync;
    }
    else if (DeviceMode == WaitingForGPS)
    {
      pS = logModeWaitingForGPS;
      iChk = chksum_logModeWaitingForGPS;
      lenS = len_logModeWaitingForGPS;
    }
    else if (DeviceMode == FatalError)
    {
      pS = logModeFatal;
      iChk = chksum_logModeFatal;
      lenS = len_logModeFatal;
    }
    else if (DeviceMode == InitMode)
    {
      pS = logModeInit;
      iChk = chksum_logModeFatal;
      lenS = len_logModeFatal;
    }
   
    // update LED mode
    //
    p = pS + lmode_logMode;
    if (LED_ON)
    {
      *p = '1';
    }
    else
    {
      *p = '0';
    }

    // update Flash Mode
    //
    p = pS + fmode_logMode;
    if (FlashMode == CLK)
    {
      *p++ = 'C';
      *p++ = 'L';
      *p = 'K';
    }
    else if (FlashMode == PPS)
    {
      *p++ = 'P';
      *p++ = 'P';
      *p = 'S';
    }
    else if (FlashMode == EXP)
    {
      *p++ = 'E';
      *p++ = 'X';
      *p = 'P';
    }
    else
    {
      *p++ = 'E';
      *p++ = 'R';
      *p = 'R';
    }

    // compute checksum
    //
    chk = chksum_b(pS,iChk-1);   // compute checksum
    btohexA(pS + iChk, chk);

    // output sentence (disallow interrupts)
    //
    noInterrupts();                                 // disallow interruption of this sentence in the log
    LogTextWrite(pS,lenS);
    interrupts();
    
    // done with this report of Mode
    //
    blnReportMode = false;      // turn OFF until next NMEA set

  }  // end of check for reporting mode

  //******************************************************
  // Output pending data from logging buffer
  //
  if (blnLogEnable)
  {

    LogFlushAll();         // flush logging buffer

  }

  //***********************
  //  now check for an incomming command from USB port
  //
  ReadCMD();
 

} // end of loop()

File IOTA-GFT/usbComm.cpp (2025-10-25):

/*
  usbComm

  Routines for parsing and executing commands sent to this flashing device via USB.  

*/

#include <Arduino.h>
#include "gpsComm.h"
#include "iota-gft.h"
#include "ublox.h"
#include "logger.h"
#include "usbComm.h"

//===========================================================================================================
//
//  GLOBAL variables and definitions
//
//===========================================================================================================

//****************************
// Command string from the PC
//
#define CommandSize 100               // max size of a command line
char strCommand[ CommandSize + 1 ];   // null terminated command line
int Cmd_Next;                         // speed optimization ( -1 => full command pending )

char idxToken[10];                    // starting index of tokens in command string - separated by spaces
int lenToken[10];                     // length of the non-blank chars in this token
int tokenCount;                       // # of tokens in string

//
// Flash settings
//
int Flash_Duration_Sec = 5;       // duration of one LED "flash" in seconds
int Pulse_Count = 5;              // # of pulses in EXP sequence


char strChk[4] = "*XX";
char strDONE[] = "[DONE]*06";   // fixed string response
char strParseError[] = "[ERROR: unable to parse command.]*52";

//===========================================================================================================
//
//   MISC FUNCTIONS
//
//===========================================================================================================

//--------------------------------------------------------------------------------------
//  ClearInputBuffer - read/clear pending data from serial port
//    Note: this code causes a delay of at least 100ms
//--------------------------------------------------------------------------------------
void ClearSerialInput()
{


  // dumb but should work to clear random data pending from the PC
  //
  for (int i = 0; i < 10; i++)
  {
    while ( Serial.available() > 0 )
    {
      Serial.read();

    } //end of reading pending data

    delay(10);
  }

} // end of ClearSerialInput

//--------------------------------------------------------------------------------------
//  FindTokens - find non-space tokens in null terminated command string
//--------------------------------------------------------------------------------------
void FindTokens()
{
  int idx;

  // init
  //
  tokenCount = 0;
  idx = 0;

  // sanity check
  //
  if (strCommand[0] == 0)
  {
    // empty command line - just leave now
    //
    return;
  }

  // walk through command string looking for non-blank tokens
  //
  while( strCommand[idx] != 0 )
  {
    // skip all blank chars to find start of a token
    //
    while (strCommand[idx] == ' ')
    {
      idx++;
    }

    // first non-blank char is null => end of string
    //    => no more tokens => leave now
    //
    if (strCommand[idx] == 0)
    {
      return;
    }

    // found a non-blank char in the string => start of new token
    //
    idxToken[tokenCount] = idx;   // save starting index of this token
    tokenCount++;                 // new token => bump count

    // now consume all non-blank chars to find end of this token
    //
    while( strCommand[idx] != ' ')
    {
      if (strCommand[idx] == 0)
      {
        // end of string => end of token, exit the loop
        //
        break;
      }
      idx++;
    }

    // we have reached the end of this token
    // record length of this token
    //
    lenToken[tokenCount-1] = (idx - idxToken[tokenCount-1]);

    // if we have room, find next token
    //
    if (tokenCount == 10)
    {
      // we only have room for 10 tokens, leave now
      //
      return;
    }

  } // end of loop through all chars of string

  // all done
  //
  return;

} // end of FindTokens

//===========================================================================================================
//
//   MANUAL OPERATIONS FUNCTIONS
//
//===========================================================================================================

//=====================================
//  ReadCMD - get input from USB port
//  
//  pick up single line "commands" sent via the USB port
//  after reading \n (newline), sets Cmd_Next = -1 and EXECUTE COMMAND
//
//  COMMANDS:
// general commands
//    status - get current device status
//    device - get device name
//    version - get version info for this device
//    null - ignore this command string if it includes the word "null" - useful for clearing the input buffer
//
// flash commands
//    flash now - start flash sequence at the next PPS or EXP pulse
//    flash duration X - X is seconds in PPS mode or starting number of pulses in EXP mode
//    flash level X - get/set the current flash intensity level [ 0 to 255]
//    flash range [X] -get/set the current range of flash intensity [ 0 to 2]
//    flash mode [pps | exp ] - get/set the current flash mode (PPS or EXP)
//
//    pulse duration [X] - get/set the flash pulse duration (us)
//    pulse interval [X] - get/set the flash pulse interval = # of exp interrupts between pulse sequences
//
//    led [ON | OFF] - turn the LED on/off right now
//
// logging commands
//    log [on | off ] - enable disable data logging (default = ON)
//
//  OUTPUTS:
//    All commands return two sentences.  Both sentences will be terminated with a CRC code. 
//    The first sentence is an echo of the command received.
//    If the command succeeds, the second sentence will be one of two forms:
//      [DONE] for commands which do not return a value (e.g. commands that set a value)
//      [command: value] where command represents the type of value returned and value is the value returned.
//    If the command fails, the second sentence will be of the form [ERROR: error description]
//
//======================================
void ReadCMD()
{
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

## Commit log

2023-11-27 removed support for SD card, reworked USB commands
    [IOTA-GFT.ino, usbComm.cpp]
2023-11-30 cleaned up several compiler errors added error reporting
    [IOTA-GFT.ino, gpsComm.h, usbComm.cpp]
2023-12-01 only report NMEA errors while in TimeValid mode
    [IOTA-GFT.ino, usbComm.cpp]
2023-12-06 Errors move to WaitingForGPS mode (to avoid hang in Sync logic when not reseting time of RMC)
    [IOTA-GFT.ino]
2024-03-02 Turn off SBAS, QZSS, and GLONASS
    [IOTA-GFT-Shield-a.brd, IOTA-GFT-Shield-a.sch]
2024-03-03 more detailed error reporting for NMEA parsing
    [gpsComm.h, ublox.cpp]
2024-03-10 implement FlashMode = LED
2024-03-10 LED ON/OFF : check for LED mode first
2024-03-10 remove LED Mode. LED ON/OFF now work in PPS mode or EXP mode.
2024-03-11 checksums on response to device commands
2024-03-11 re-enable system interrupts in PPS and EXP ISRs
2024-03-11 re-enable interrupts in Timer3 output compare ISR
2024-03-11 added option checksum to device commands
2024-03-11 EXP ISR - re-enable ints AFTER starting LED
2024-03-12 added checksum to a couple of messages. moved SendResponse to logger.cpp
2024-03-13 cleared interrupts around logging again to avoid interrupting logging sentences
    [IOTA-GFT.ino, usbComm.cpp]
2024-03-13 fixed check of incoming checksum with commands. updated version number.
    [IOTA-GFT.ino, usbComm.cpp]
2024-04-01 bug fix: pps code was logging the time of the previous pps
    [IOTA-GFT.ino]
2024-05-04 more documentation revised board file of shield to put component values in tNames (silkscreen)
    [IOTA-GFT-Shield-a.brd]
2025-04-08 Primarily changes to the sentences returned in response to a USB command to the device.
2025-10-13 changed Mode output sentence to include current status of LED
2025-10-25 small doc change IOTA-GFT.ino - remove unused variables and fixup check of tk_PPS
    [IOTA-GFT.ino]
2025-10-25 fixed init of timer 3 to clear compare interrupts by writing a 1 instead of 0 to TIFR3 bits
    [IOTA-GFT.ino, usbComm.cpp]

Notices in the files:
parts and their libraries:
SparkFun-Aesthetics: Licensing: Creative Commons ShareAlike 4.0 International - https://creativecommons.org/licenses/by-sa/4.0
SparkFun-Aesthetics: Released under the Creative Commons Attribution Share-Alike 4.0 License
